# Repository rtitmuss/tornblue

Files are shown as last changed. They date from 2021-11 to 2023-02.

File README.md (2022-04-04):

# TornBlue - a bluetooth split keyboard

In this repo you can find information about the TornBlue a bluetooth split keyboard with SMT components. This is an iteration on the [Torn](https://github.com/rtitmuss/torn), which is a split keyboard using through hole components.

You can ask questions and get help on the [Torn Discord channel](https://discord.gg/mamAqNccju).

**WARNING: These files are provided as a reference for designing keyboard PCBs, without liability and without any guarantees regarding functionality. This is untested work in progress, really don't assume anything here will work.**

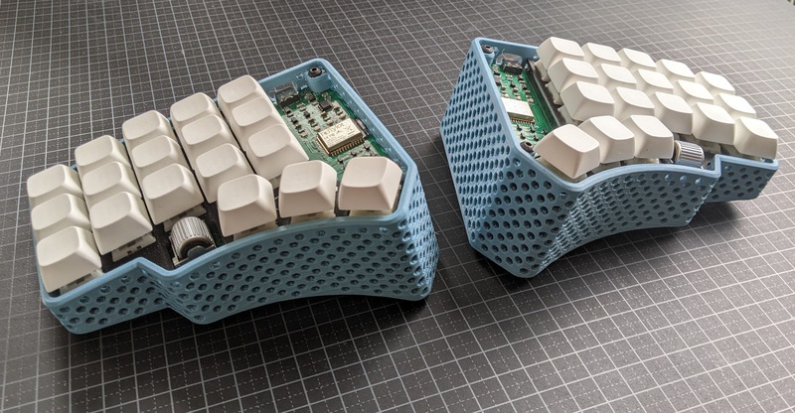
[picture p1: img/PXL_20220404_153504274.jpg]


## Features

- nRF52840 using [zmk](https://zmk.dev/) keyboard firmware
- Battery charging for a 3.7v lithium rechargeable battery (JST-PH connector)
- 6x3 or 5x3 layout with detachable outer column
- 3 leds and 1 charging led
-  ([SOIC test clip footprint](https://hackaday.com/2019/06/13/soicbite-a-program-debug-connector-for-an-soic-test-clip/)) for programming
- Breakout with switchable 3.3v and gpios
- Battery level reported over BT
- Supports soldered Cherry MX compatible or Kailh Choc key switches
- Horizontal reset button (case friendly) 
- JLCPCB PCBA (pcb assembly); handsoldering required for underglow leds and JST-PH connector 

Optional features:

- Underglow leds 
- Optional Panasonic EVQWGD001 wheel encoders

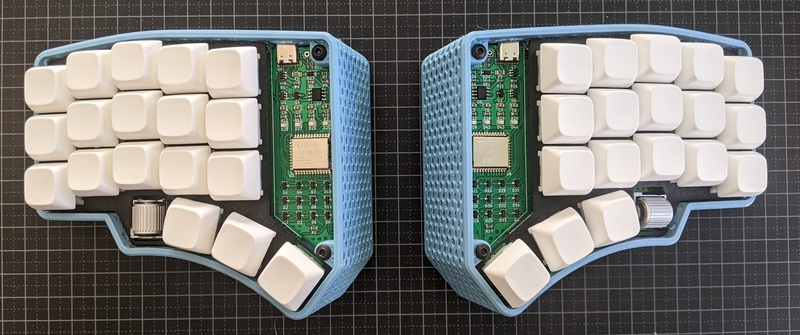
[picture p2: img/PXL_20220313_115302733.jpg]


## Parts required

- 2x assembled TornBlue Rev 1 PCBs
- 2x 3.7v lithium rechargeable battery with JST connector. **SAFETY NOTE: Only use a LiIon battery with over-charging and over-use protection. Check the battery polarity before connecting.**
- (Optional) 2x [JST-PH connector](https://www.electrokit.com/en/product/header-ph-2p-2mm-right-angle-smd/). 2mm pitch. Side entry. Surface-mounted.
- (Optional) 2 x [Panasonic EVQWGD001](https://www.aliexpress.com/wholesale?catId=0&initiative_id=SB_20210830111528&SearchText=Panasonic+EVQWGD001) wheel encoder
- (Optional) 12 x [WS2812B 5050 leds](https://www.aliexpress.com/wholesale?catId=0&initiative_id=SB_20210830111716&SearchText=WS2812B)
- (Optional) ST link v2 (or similar) and SOIC-8 test clip for programming the bootloader

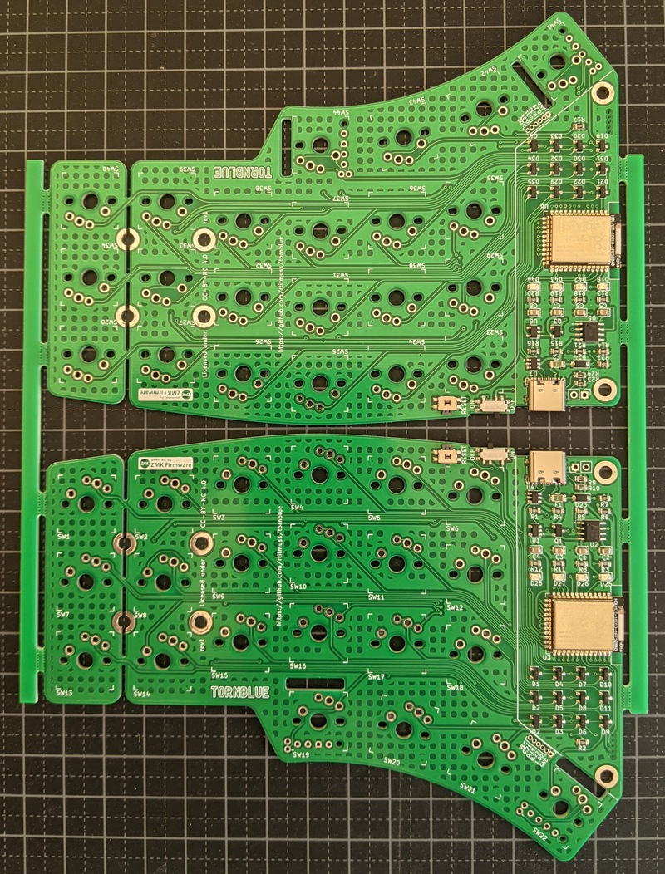
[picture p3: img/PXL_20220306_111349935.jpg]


## Build instructions

You can find full [build instructions](./build.md), and information for [different cases](./case/README.md).

## Components

The main components are:

- [Holyiot YJ-18010](http://www.holyiot.com/tp/2019042516322180424.pdf); this was chosen as it has castellated edges, which is easier hand soldering the module to the PCB.

- [XC6220](https://www.torexsemi.com/file/xc6220/XC6220.pdf); 3.3V voltage regulator to supply the Holyiot module.

- [TP4096](https://dlnmh9ip6v2uc.cloudfront.net/datasheets/Prototyping/TP4056.pdf) Li-Ion Battery Charger 

- [SRV05-4](https://www.onsemi.com/pdf/datasheet/srv05-4-d.pdf) ESD protection for the USB port
   
 - Other parts use 0805 and SOT-23 packages. These larger packages can be hand soldered and are similar sizes for a pleasing appearance. The parts have been laid out horizontally with a consistent polarity to simplify assembly.

## Reference designs

The following projects were used as reference designs.

- [ZMK hardware design guide](https://github.com/ebastler/zmk-designguide) (CERN Open Hardware Licence Version 2 - Permissive) - note the battery charging circuit might be unsafe, see this information about [TP4056](https://www.best-microcontroller-projects.com/tp4056.html)

- [isometria75](https://github.com/ebastler/isometria-75/tree/v2) (BSD 2-Clause License)

- [Unified USB type-C PCB](https://github.com/ebastler/unified-usb-pcb) (BSD 2-Clause License)

- [Nice!Nano](https://nicekeyboards.com/docs/nice-nano/pinout-schematic)

- [nRFMicro](https://github.com/joric/nrfmicro/wiki) (Public domain)

- [Adafruit nRF52840](https://learn.adafruit.com/introducing-the-adafruit-nrf52840-feather/downloads) (Creative Commons Attribution, Share-Alike)

## Showcase

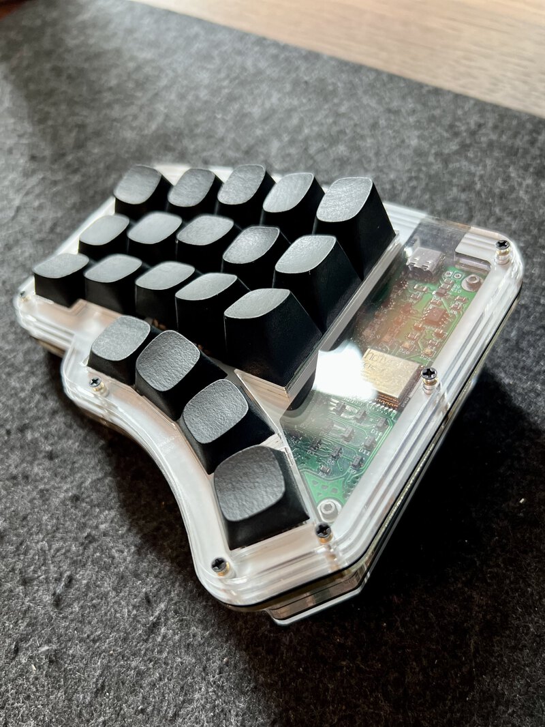
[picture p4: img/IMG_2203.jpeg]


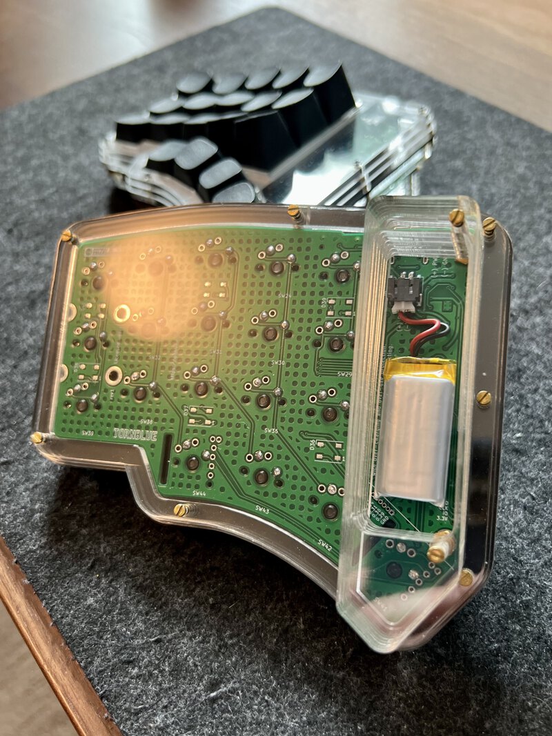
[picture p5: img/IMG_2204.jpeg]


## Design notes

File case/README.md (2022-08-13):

# Tornblue cases

The following case designs are available for Tornblue.

## 3D printed wedge case

This is a hi-pro style wedge case. You can download the [files and instructions](./wedge/README.md).



## Stacked Acrlyic Case

You can download the [files and instructions](./stacked-acrylic/README.md).

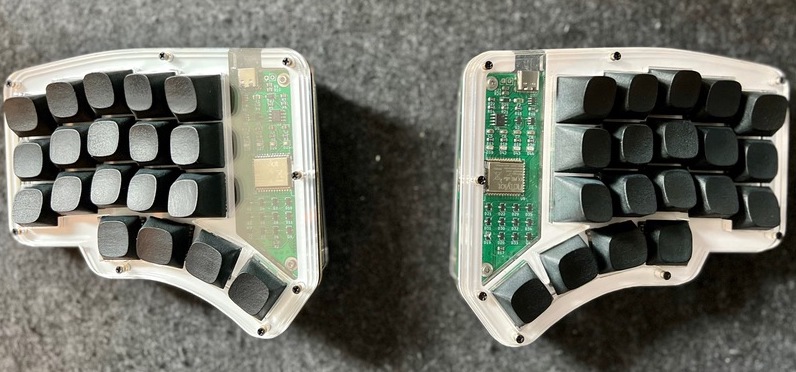
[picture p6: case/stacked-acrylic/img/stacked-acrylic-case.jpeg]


## Mini Wedge Case

This is a plateless wedge case. You can download the [files and instructions](./mini-wedge/README.md).

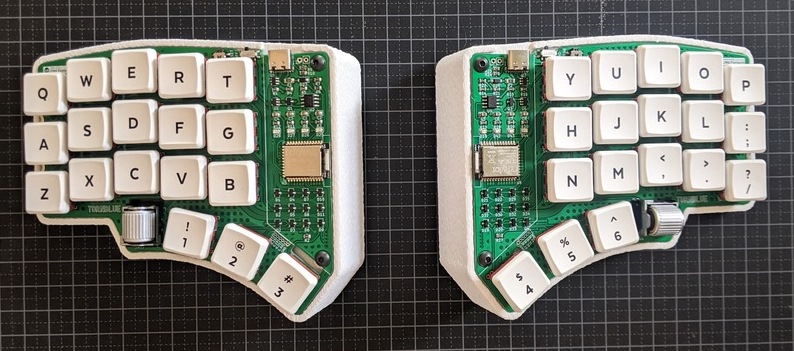
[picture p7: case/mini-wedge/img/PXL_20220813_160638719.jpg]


## Fusion 360 design files

If you want to make your own case designyou can use this [fusion 360 design file](./fusion360/tornblue r1.f3d). This design includes the KiCad 3d model and a basic sketch for the keyboard.

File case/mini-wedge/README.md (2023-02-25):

# Mini Wedge Case

This is a plateless wedge style case with a 14 degree angle for 5 column tornblue keyboards.

## 3d printing

### Case

You can 3d print a mini wedge case for your Tornblue using the follow files:

#### 5 column case
[Mini Wedge 5 column.3mf](Tornblue_Mini_Wedge_5col.3mf)

#### 6 column case
[Mini Wedge 6 column.3mf](Tornblue_Mini_Wedge_6col.3mf)

No supports are required for the base. Print the case as a mirror image for the right side. When the case has printed you need to add four M3 heat set inserts in the bottom of each half of the case. The prints below use a 'fuzzy skin' to add some texture to the sides of the case.

## Weights

You can optionally add up to 135g of weight in the bottom of the case. The case is designed to use car wheel balance weights, with sizes 10g: 23mm x 19mm. 5g: 12mm x 19mm. Height 4mm (including adhesive padding). For example: [US](https://www.amazon.com/Pit-Posse-Balancing-Weights-Adhesive/dp/B00OQWS98S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), [UK](https://www.amazon.co.uk/FIERCE-CYCLE-Balance-Weights-Motorcycle/dp/B07QQ539GV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), [SE](https://www.amazon.se/gp/product/B01GHKG18G/ref=ppx_yo_dt_b_asin_image_o00_s00?ie=UTF8&psc=1).

## Assembly

Place the completed PCB on the base, taking care not to trap the battery cable. Use four 6mm M3 button head screws to attach the PCB to the base. Add adhesive feet to the underneath of the case.

Your keyboard is now finished, enjoy!


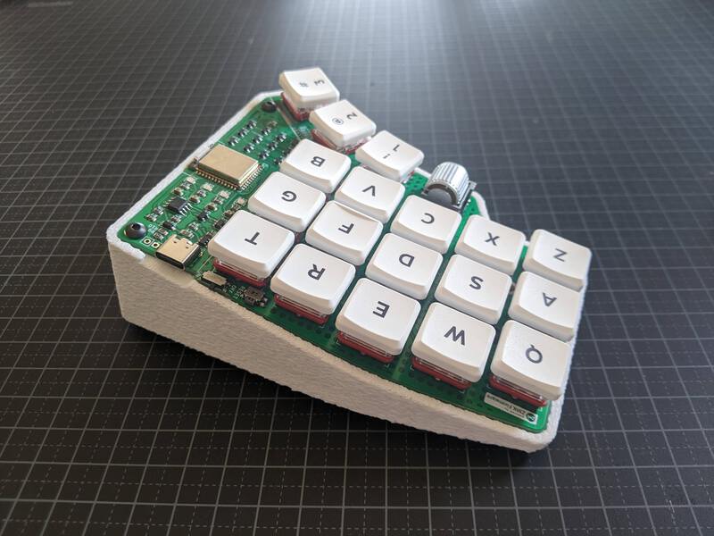
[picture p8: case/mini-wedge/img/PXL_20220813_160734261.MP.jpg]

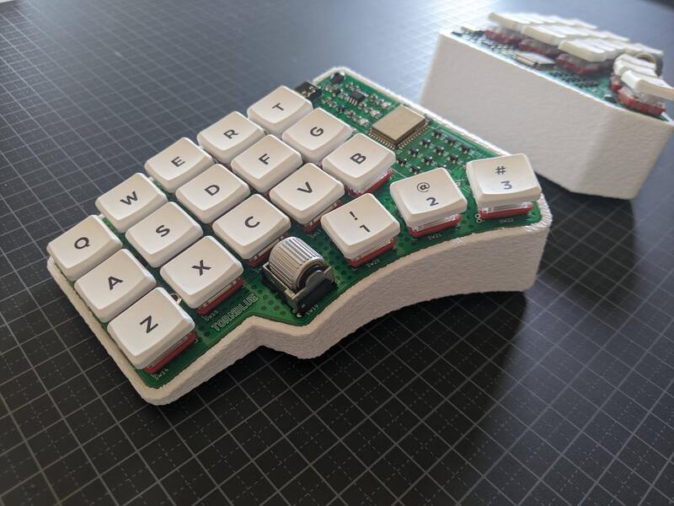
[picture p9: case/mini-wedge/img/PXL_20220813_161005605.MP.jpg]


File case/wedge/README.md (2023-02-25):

# 3d Printed Wedge Case

This is a wedge style case with a 14 degree angle for 5 column tornblue keyboards.

## 3d printing

### Plate

There is an optional 3d printable plate for MX switches. Remember to print and fit this before soldering your switches. The plate has cutouts for the roller encoder.

#### 5 column plate
[Wedge 5 column Plate.3mf](Tornblue_Wedge_5col_Plate.3mf)

#### 6 column plate
[Wedge 6 column Plate.3mf](Tornblue_Wedge_6col_Plate.3mf)

### Case

You can 3d print a wedge case for your Tornblue using the follow files:

No supports are required for the base.

The edge prints upside down so the visible surface is on the print bed. You need to print with supports.

#### 5 column case
[Wedge 5 column Base.3mf](Tornblue_Wedge_5col_Base.3mf)

[Wedge 5 column Edge.3mf](Tornblue_Wedge_5col_Edge.3mf)

#### 6 column case
[Wedge 6 column Base.3mf](Tornblue_Wedge_6col_Base.3mf)

[Wedge 6 column Edge.3mf](Tornblue_Wedge_6col_Edge.3mf)

## Post processing

You need to do some post processing on the case wall. Remove the support from the top of the case and clean up the bridging by the USB connector and switch holes. Give the case a good rub to remove any stray fibers.

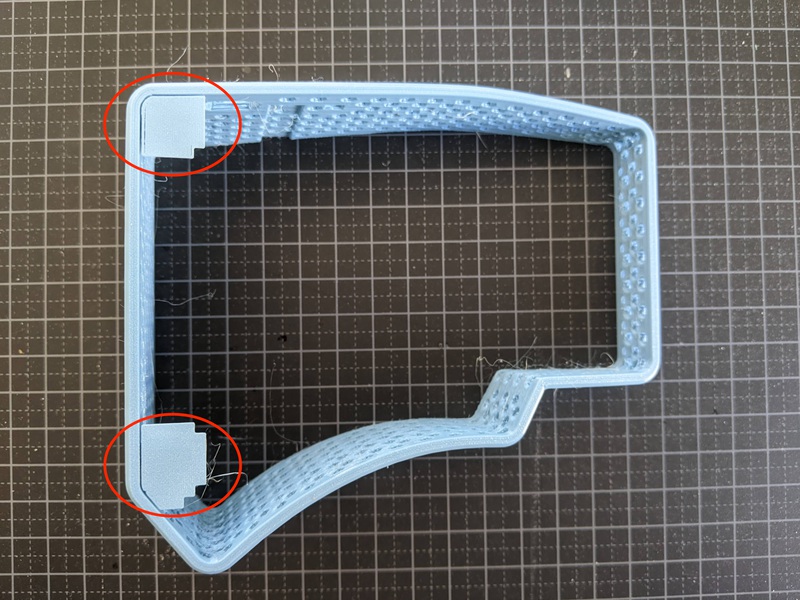
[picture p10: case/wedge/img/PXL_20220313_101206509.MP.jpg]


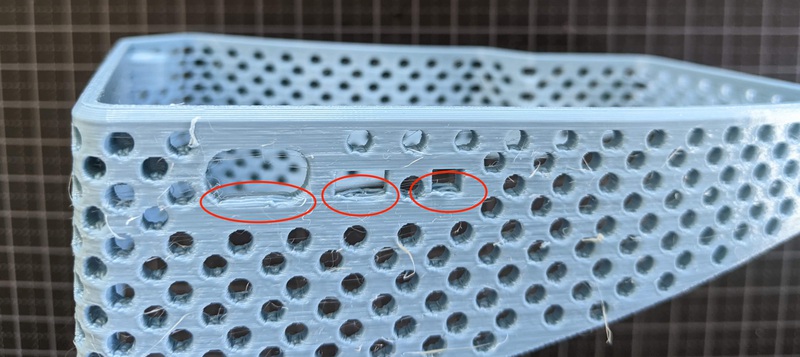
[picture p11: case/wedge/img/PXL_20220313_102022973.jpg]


Add four M3 heat set inserts in the bottom of each half of the case.

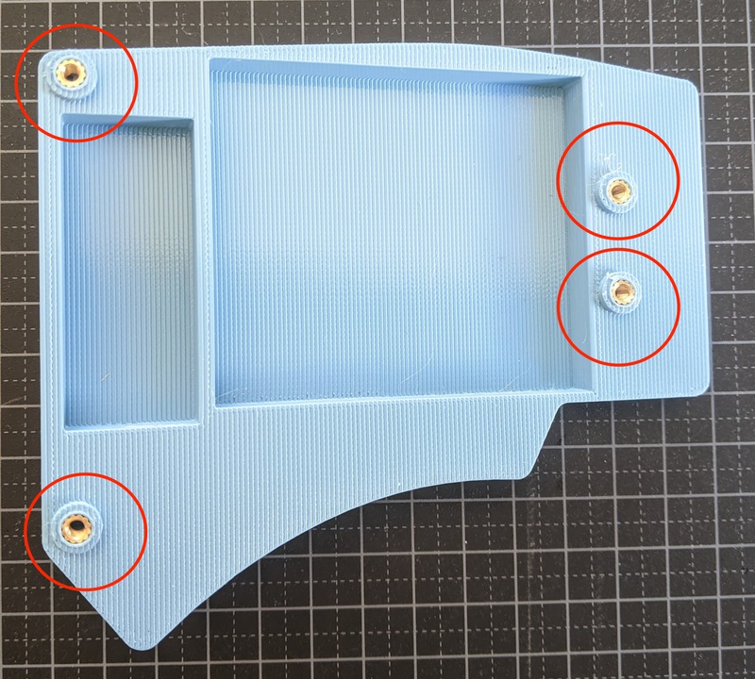
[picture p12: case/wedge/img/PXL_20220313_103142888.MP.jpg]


## Weights

You can optionally add up to 180g of weight in the bottom of the case. The case is designed to use car wheel balance weights, with sizes 10g: 23mm x 19mm. 5g: 12mm x 19mm. Height 4mm (including adhesive padding). For example: [US](https://www.amazon.com/Pit-Posse-Balancing-Weights-Adhesive/dp/B00OQWS98S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), [UK](https://www.amazon.co.uk/FIERCE-CYCLE-Balance-Weights-Motorcycle/dp/B07QQ539GV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), [SE](https://www.amazon.se/gp/product/B01GHKG18G/ref=ppx_yo_dt_b_asin_image_o00_s00?ie=UTF8&psc=1).

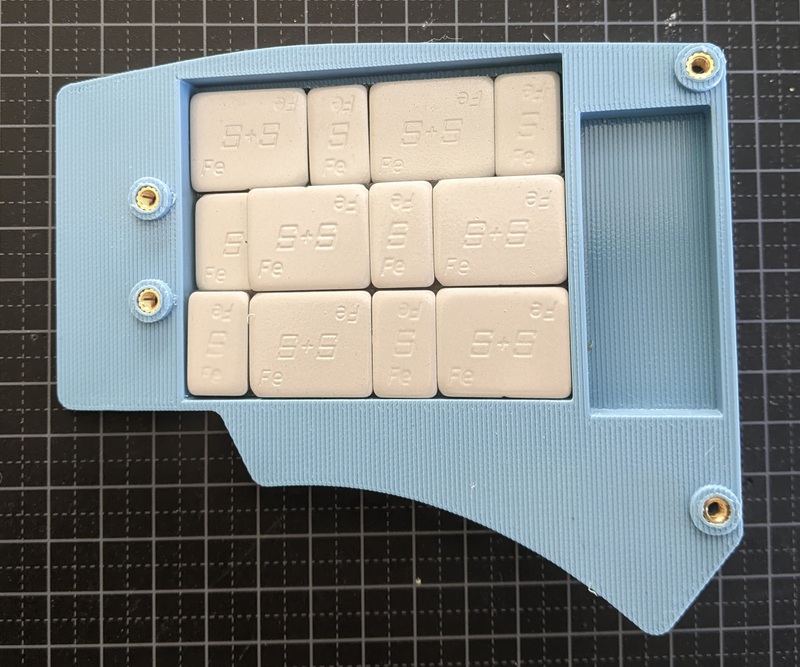
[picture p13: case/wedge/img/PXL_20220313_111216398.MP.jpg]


## Assembly

Place the completed PCB on the base, taking care not to trap the battery cable. Use two 6mm M3 button head screws to attach the PCB to the base as shown below.

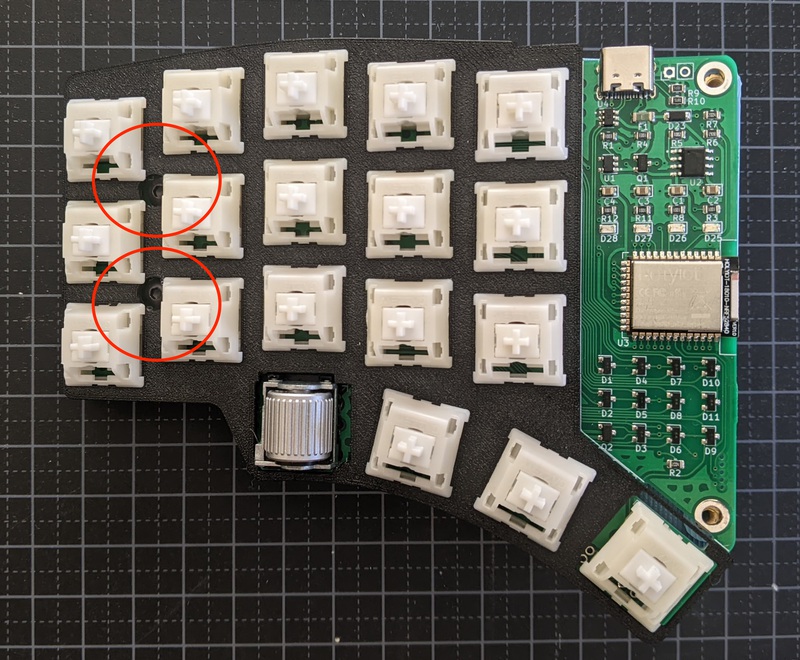
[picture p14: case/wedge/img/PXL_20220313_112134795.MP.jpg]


Carefully slide the case wall over the base. Check the clearance near the on/off switch. Use two 16mm M3 button head screws to swecure the top of the case.

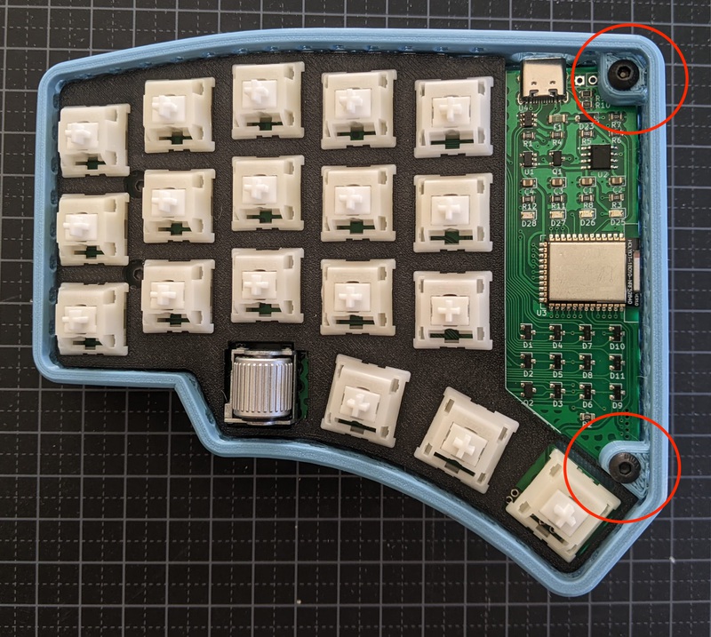
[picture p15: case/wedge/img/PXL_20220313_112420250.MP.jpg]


Add adhesive feet to the underneath of the case.

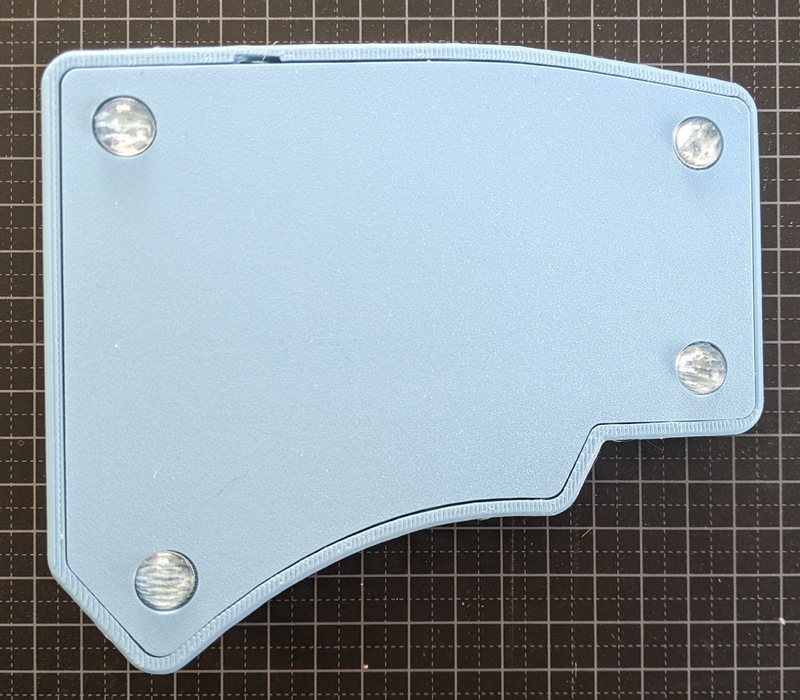
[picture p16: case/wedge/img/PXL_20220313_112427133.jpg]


Your keyboard is now finished, enjoy!



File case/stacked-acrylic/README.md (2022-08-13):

# Stacked Acrylic Plate Case

This is a high-profile case made of a stack of laser-cut acrylic/metal sheets. It supports a 5 column TornBlue keyboard. An optional stack of layers can be used to add tenting and store the battery.

With the exception of the switch plate, each layer is cut from 3mm acrylic. The switch plate is 1.5-1.6mm and can be cut from either acrylic or metal.

[Fusion 360 File](./StackedAcrylicCase.f3d)

In addition to the layers you will need screws and standoffs to mount the layers:

- 40 M3 x 6mm screws
- 16 M3 x 12mm standoffs

For the tenting legs you will need:

- 8 M3 x 6mm screws
- 4 M3 x 21mm standoffs (may need to adjust if you add or remove layers)

## Images


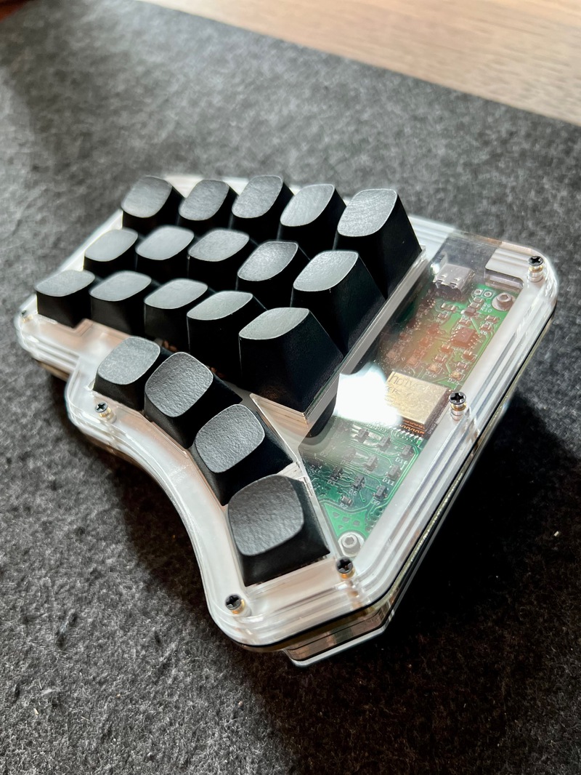
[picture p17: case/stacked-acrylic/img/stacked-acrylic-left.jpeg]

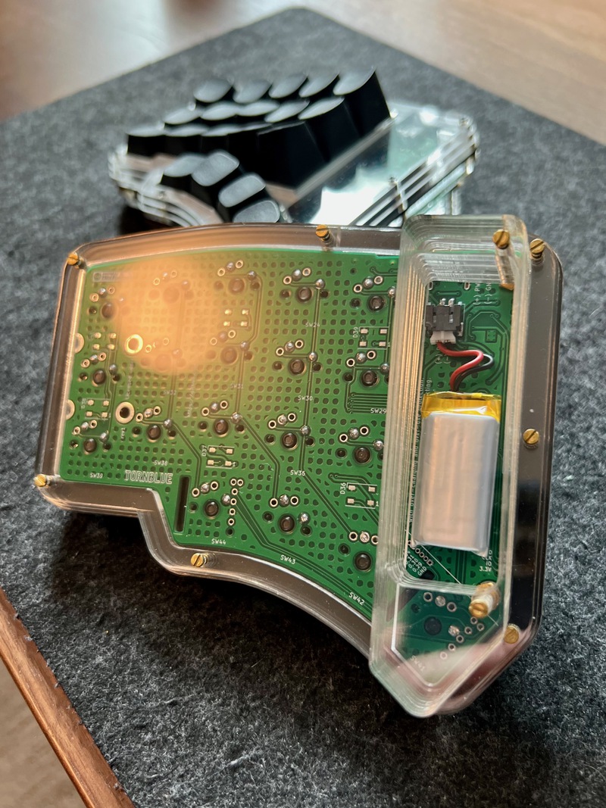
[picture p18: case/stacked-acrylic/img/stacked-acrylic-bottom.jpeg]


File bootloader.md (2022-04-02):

# Bootloader

There are main options for programming nRF52540 boards, and these are well documented at [https://github.com/joric/nrfmicro/wiki/Bootloader](https://github.com/joric/nrfmicro/wiki/Bootloader). To program the tornblue I used a ST-Link/V2 with the Blackmagic firmware on OS X.

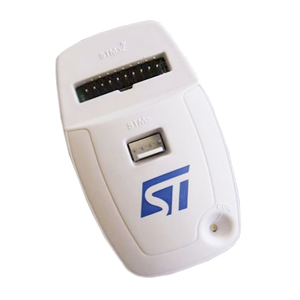
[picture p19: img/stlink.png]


## Installing the blackmagic firmware
To install the blackmagic firmware on the ST-Link/V2 you need to first download and compile the following tool and firmware:

-   [https://github.com/UweBonnes/stlink-tool/tree/stlinkv21](https://github.com/UweBonnes/stlink-tool/tree/stlinkv21)
-   [https://github.com/blacksphere/blackmagic/tree/master/src/platforms/stlink](https://github.com/blacksphere/blackmagic/tree/master/src/platforms/stlink)

Install the blackmagic firmware on the ST-Link/V2 using:

	$ ./stlink-tool/stlink-tool blackmagic/src/blackmagic.bin
	Firmware version : V2J31S7 
	Loader version : 14152 
	ST-Link ID : 52FF68064885555248171987 
	Firmware encryption key : A32E6E6E82ADAF7D99EBD574CB4C784D 
	Current mode : 1 Loaded firmware : blackmagic/src/blackmagic.bin, size : 97332 bytes 
	................................................................................................

# Tornblue bootloader

Like many ZMK boards Tornblue uses the Adafruit_nRF52_Bootloader. I modified this for tornblue so that one LED is enabled in the bootloader. You can download this version from [https://github.com/rtitmuss/Adafruit_nRF52_Bootloader](https://github.com/rtitmuss/Adafruit_nRF52_Bootloader).

Compile the bootloader using:

	$ make BOARD=tornblue

You can find the compiled bootloader at:

	_build/build-tornblue/tornblue_bootloader-0.6.3-49-gbfd3b24.out

# Connecting the programmer

You can connect the programmer to the tornblue using a SOIC connector. Connect the SWD pads on the PCB to the 20 pin JTAG header on the ST-Link/V2 as follows:  

|PCB SWD|ST-Link/V2  |  
|--|--|
|3.3V|VCC Pin 1|  
|SWD IO|SWDIO Pin 7|  
|SWD CLK|SWCLK Pin 9|  
|GND|GND Pin 8|

The pinout on the ST-Link/V2 20 pin JTAG header is:

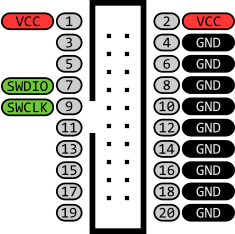
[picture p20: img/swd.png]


# Programming the bootloader

You always need to setup the ST-Link/V2 after it has been powered up using:

    ./stlink-tool/stlink-tool 

When the ST-Link/V2 is first connected all the three green LEDs on the Tornblue may all be lit.

You can first check the that board is correctly connected using `swdp_scan` as shown below. You may need to update the /dev path.

    $ arm-none-eabi-gdb --batch -ex "target extended-remote /dev/cu.usbmodem14101" -ex "mon swdp_scan"
    Target voltage: 3.30V
    Available Targets:
    No. Att Driver
     1      Nordic nRF52 Access Port (protected)
     
You can then program the bootloader, using:

    $ arm-none-eabi-gdb --batch -ex "target extended-remote /dev/cu.usbmodem14101" -ex "mon swdp_scan" -ex "file tornblue_bootloader-0.6.3-49-gbfd3b24_s140_6.1.1.hex" -ex "att 1" -ex "mon erase" -ex load
    Target voltage: 3.30V
    Available Targets:
    No. Att Driver
     1      Nordic nRF52 Access Port (protected) 
    warning: while parsing target description: no element found
    warning: Could not load XML target description; ignoring
    warning: while parsing target memory map (at line 1): Required element <memory> is missing
    0xbfefed14 in ?? ()
    Loading section .sec1, size 0xb00 lma 0x0
    Loading section .sec2, size 0xf000 lma 0x1000
    Loading section .sec3, size 0x10000 lma 0x10000
    Loading section .sec4, size 0x5de8 lma 0x20000
    Loading section .sec5, size 0x85b4 lma 0xf4000
    Loading section .sec6, size 0x58 lma 0xfd800
    Loading section .sec7, size 0x8 lma 0x10001014
    Start address 0xfafcc, load size 188156
    Transfer rate: 418 KB/sec, 969 bytes/write.
    [Inferior 1 (Remote target) detached]

I found that I needed to program the bootloader twice for it to be successful.

    $ arm-none-eabi-gdb --batch -ex "target extended-remote /dev/cu.usbmodem14101" -ex "mon swdp_scan" -ex "file tornblue_bootloader-0.6.3-49-gbfd3b24_s140_6.1.1.hex" -ex "att 1" -ex "mon erase" -ex load
    Target voltage: 3.30V
    Available Targets:
    No. Att Driver
     1      Nordic nRF52 M4
     2      Nordic nRF52 Access Port 
    0xfffffffe in ?? ()
    erase..
    Loading section .sec1, size 0xb00 lma 0x0
    Loading section .sec2, size 0xf000 lma 0x1000
    Loading section .sec3, size 0x10000 lma 0x10000
    Loading section .sec4, size 0x5de8 lma 0x20000
    Loading section .sec5, size 0x85b4 lma 0xf4000
    Loading section .sec6, size 0x58 lma 0xfd800
    Loading section .sec7, size 0x8 lma 0x10001014
    Start address 0xfafcc, load size 188156
    Transfer rate: 31 KB/sec, 959 bytes/write.
    [Inferior 1 (Remote target) detached]

When the booloader has been successfully installed then the a single green LED will be lit.

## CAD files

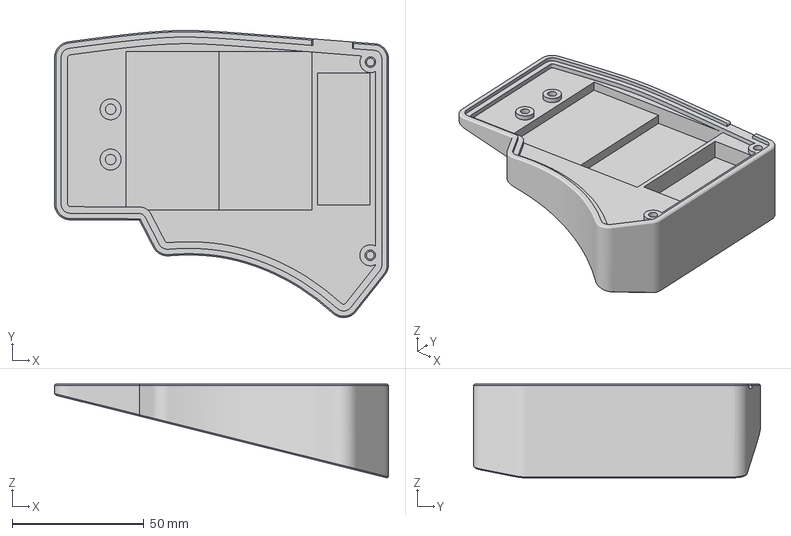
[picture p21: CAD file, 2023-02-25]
case/mini-wedge/Tornblue_Mini_Wedge_5col.3mf
126.7 x 108.9 x 35.6 mm

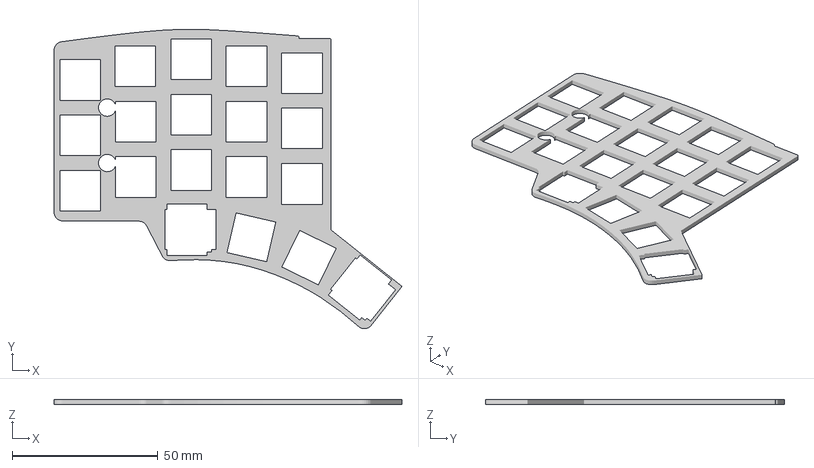
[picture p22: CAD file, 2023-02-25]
case/wedge/Tornblue_Wedge_5col_Plate.3mf
119.6 x 102.9 x 1.60 mm

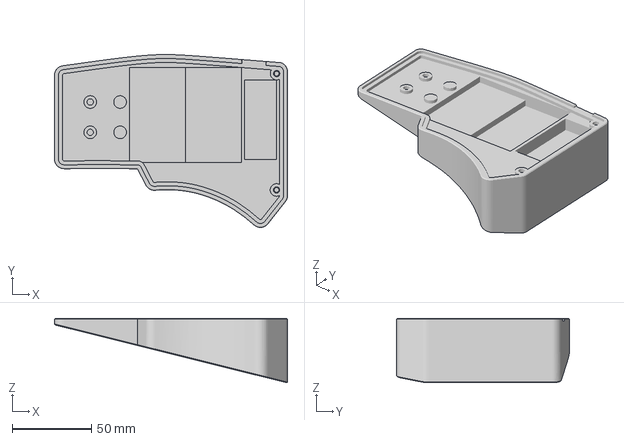
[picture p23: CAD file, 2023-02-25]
case/mini-wedge/Tornblue_Mini_Wedge_6col.3mf
146.7 x 108.9 x 40.6 mm

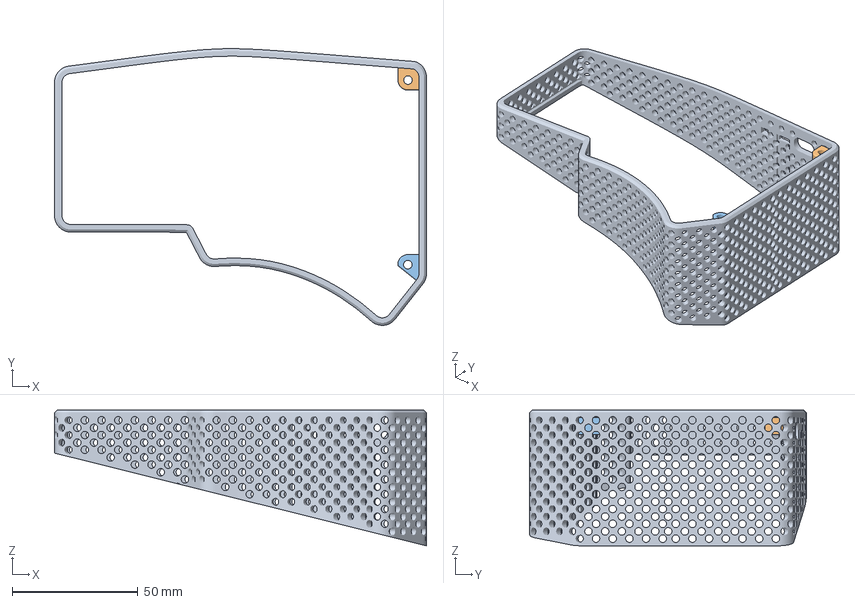
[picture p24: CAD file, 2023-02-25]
case/wedge/Tornblue_Wedge_6col_Edge.3mf
147.7 x 109.9 x 53.9 mm

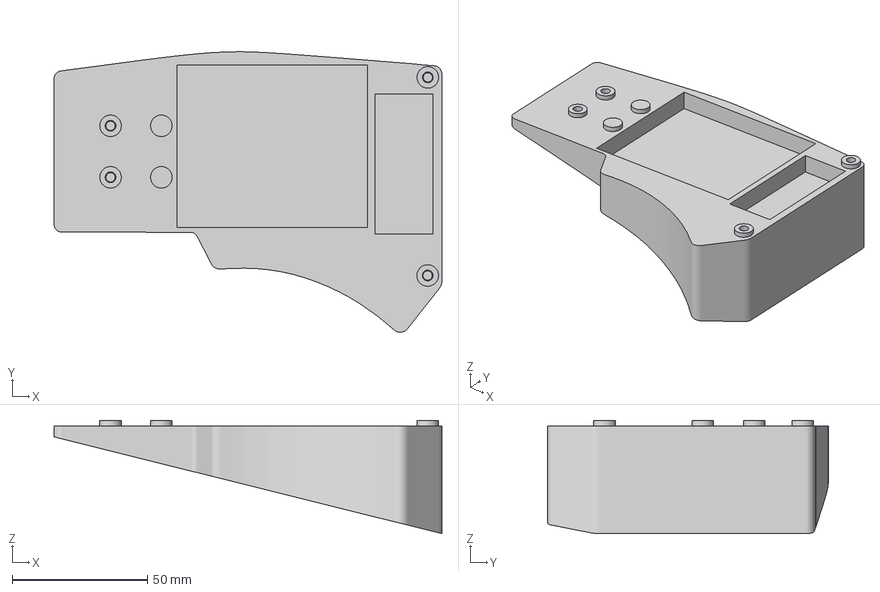
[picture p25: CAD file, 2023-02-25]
case/wedge/Tornblue_Wedge_6col_Base.3mf
143.5 x 103.8 x 41.9 mm

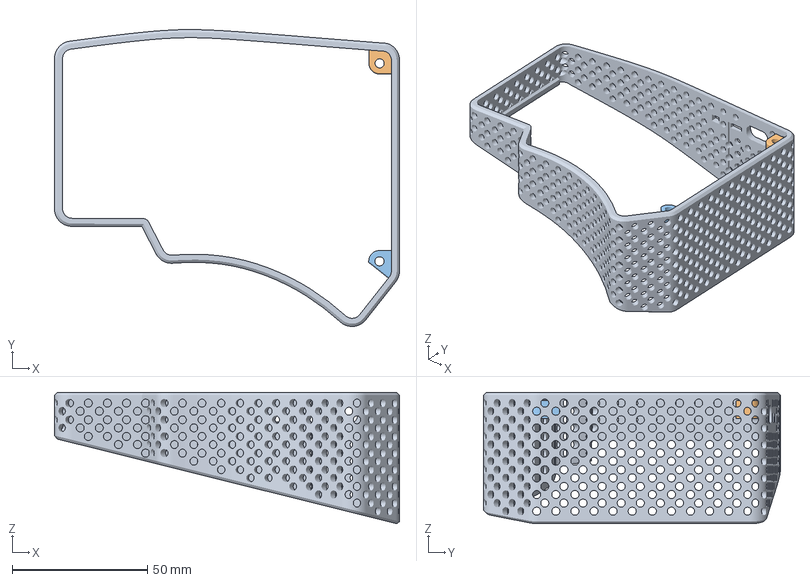
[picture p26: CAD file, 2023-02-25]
case/wedge/Tornblue_Wedge_5col_Edge.3mf
127.7 x 109.9 x 48.6 mm

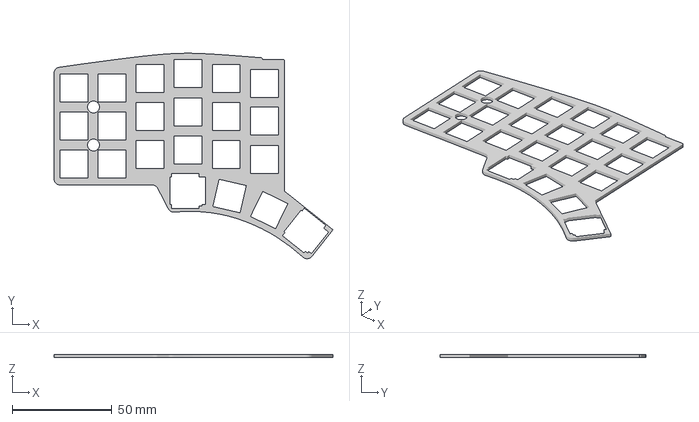
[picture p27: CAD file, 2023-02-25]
case/wedge/Tornblue_Wedge_6col_Plate.3mf
139.6 x 102.9 x 1.60 mm

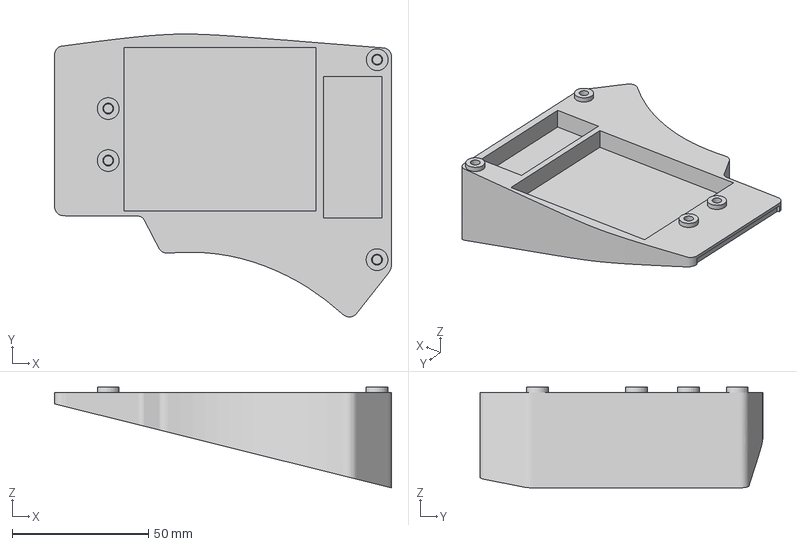
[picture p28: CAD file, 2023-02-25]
case/wedge/Tornblue_Wedge_5col_Base.3mf
123.5 x 103.7 x 36.9 mm

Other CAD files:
case/fusion360/tornblue r1.f3d
case/stacked-acrylic/StackedAcrylicCase.f3d

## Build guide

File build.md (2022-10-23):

# Build Instructions

There are the build instructions for the Tornblue keyboard.

## PCBs

The PCBs have been ordered using PCBA, or PCB assembly. This means that most components have been installed during manufacturing.

There are some optional components that need to be hand soldered on the underside of the board, the JST-PH battery connector and underglow LEDs. You will also need to solder the keyswitches and optional roller encoders.

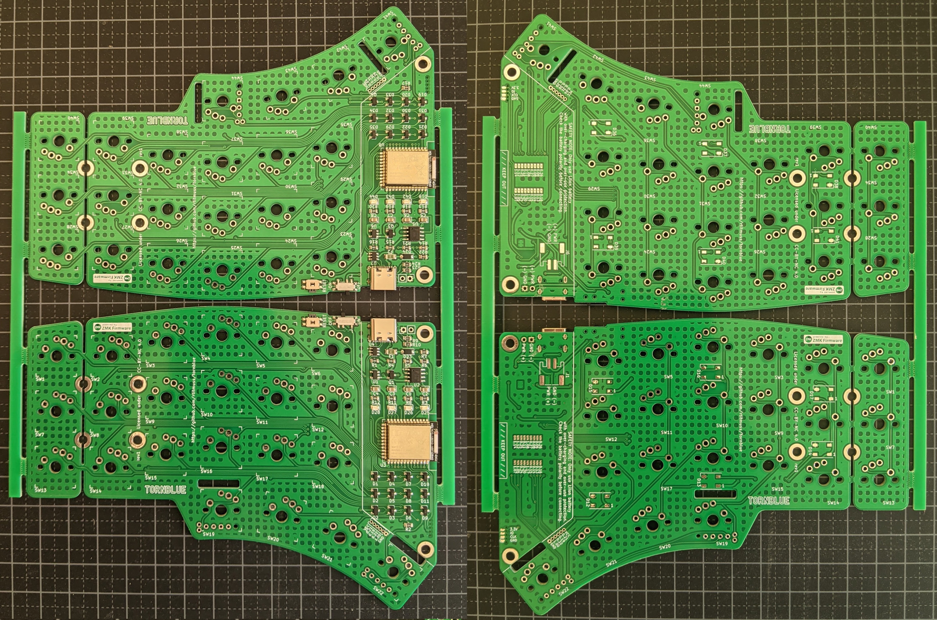
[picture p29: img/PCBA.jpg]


### Depanelization 

The left and right PCBs have been manufactured as a single panel. First you need to remove the breakaway tabs, to get a clean cut you can use wire cutters and a file (for example see this [PCB Depaneling](https://www.youtube.com/watch?v=NLKeF43AOBY&t=121s) video).

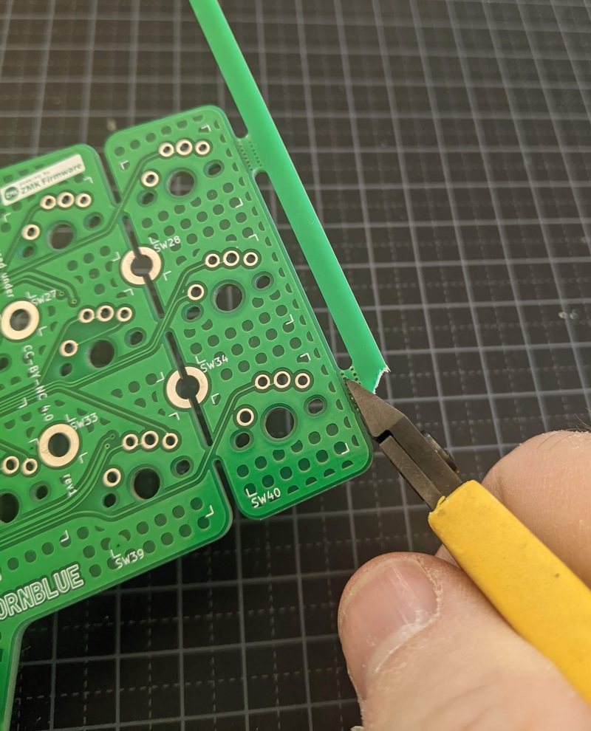
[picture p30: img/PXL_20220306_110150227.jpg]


### 5 or 6 columns

If you are building a 5 column Tornblue keyboard you also need to break off the outer column.

### Underglow LEDs (optional)

The WS2812B 5050 leds need to be soldered in the **correct orientation**, on the underside of the board. There is a mark on one corner of the leds, this should be pointing to the top left of the PCB - next to the small vertical mark on the silkscreen. Carefully solder all six WS2812B leds.

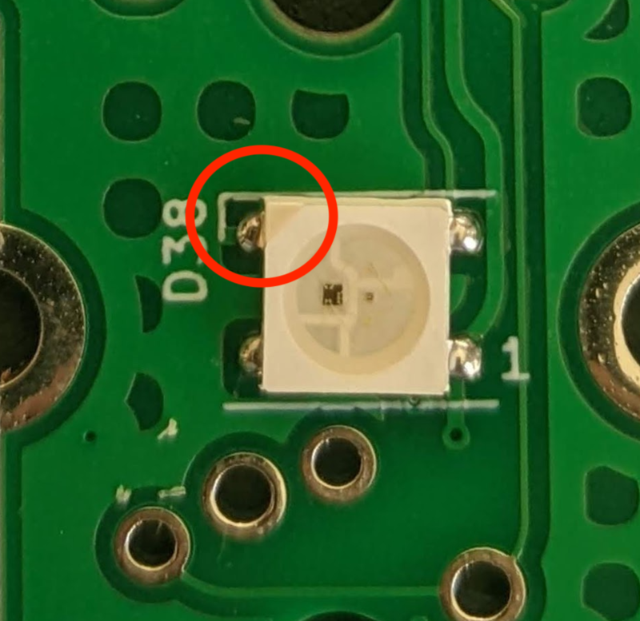
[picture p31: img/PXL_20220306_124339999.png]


### JST-PH connector (optional)

The JST-PH connector can be used for the battery connection, it is also possible to solder the battery with the through hole connectors near the USB port. **Do not connect the battery yet!**

The JST-PH connector is soldered on the underneath of the PCB.  The two pads towards the top of the board connect the battery, and the lower two pads are for mechanical support.

First apply some solder to one of the pads (as shown in the picture below). Reheat the solder and slide the JST-PH connector in place. Check the connector is correctly positioned, and adjust if required. Then solder the remaining three pads.

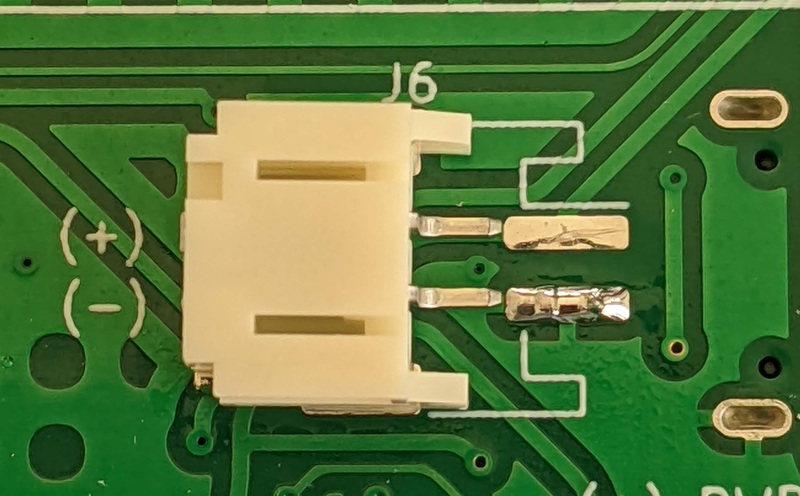
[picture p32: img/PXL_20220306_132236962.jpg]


## Bootloader

If you bought boards directly from rtitmuss then bootloader is pre-programmed on the board. 

If you are using your own boards then you will need to program the bootloader yourself before installing ZMK. [See how to program the bootloader](./bootloader.md). 

## ZMK

You can now install zmk.



_The tornblue board configuration is not yet included in the zmk repo, you need to download zmk from https://github.com/rtitmuss/zmk_

#### Building with github actions

(todo)

#### Building on your PC

To build the firmware on your PC follow the [zmk installation instructions](https://zmk.dev/docs/development/setup).

Once thats done, checkout tornblue and move to the /app dir
	
	git checkout tornblue_r1
	cd app

You can build zmk for the left side of the keyboard using:

	west build -p -d build/tornblue_left -b tornblue_left -- -DZMK_CONFIG=/Users/richardt/keyboard/miryoku-zmk-config/config/

You can build zmk for the right side of the keyboard using:

	west build -p -d build/tornblue_right -b tornblue_right

### Install zmk

Connect the left side of the keyboard with USB. Press the reset button quickly twice. You should see a USB drive called `NRF52BOOT`. Copy the `zmk.uf2` from the `tornblue_left` build folder. zmk will be installed and the keyboard will restart.

Repeat this with the right side of the keyboard, but copy the `zmk.uf2` file from the `tornblue_right` build folder.

### Test

You can now test the PCBs. Power both sides of your keyboard to your PC with two USB cables Use tweezers or similar to short the key switch pads and test that all the keys work, on both sides of the keyboard. Note you don't need to pair the bluetooth yet the keycodes will be sent over USB.

## Key switches and battery

### Encoder (optional)

You can optionally use a Panasonic EVQWGD001 horizontal encoder. Position the encoder clip at an angle on the PCB, and carefully rotate it down. Solder the pins.

_ZMK currently only supports the encoder on the left side of the keyboard. A patch is needed to support encoders on both sides._

### Key switches

You can solder either Cherry MX compatible or Kailh Choc key switches. If you plan to use a plate remember to insert the key switches before soldering.

### Battery

If you are using the JSP PH connector you can now plug your battery on the underside of the PCB. **The red wire MUST connect to the positive terminal marked 'PWR (+)'**.

Alternatively you can solder the battery directly to the PCB using the through holes near the USB connector. **Be  very careful not to short the battery connectors.**

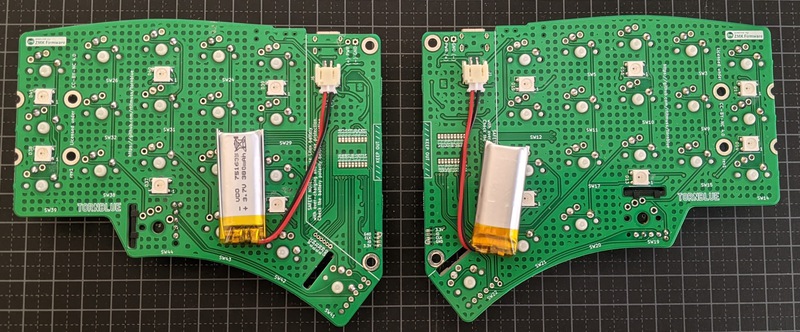
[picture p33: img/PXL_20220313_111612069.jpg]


## Your finished

The PCB assembly if now complete. You can use one of the [case designs](./case/README.md), or make your own.

You can now use your new Bluetooth tornblue keyboard by pairing it with your PC, and customising zmk as required.

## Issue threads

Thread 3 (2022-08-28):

Question: Coin battery Fork

rafaeldelboni, 2022-08-28:
I was planning to build this project to make a single PCB keyboard with choc switches (ferris like), but with the current battery is very hard to have something nice looking without the case.

So I was thinking to fork this and replace the current battery and use a coin battery in the space of the rotary encoder.

Lithium Battery CR2032 210mAh
https://a.aliexpress.com/_mOBfcmy

Battery Holder
https://a.aliexpress.com/_mt0Ty5w

Do you think is possible? How hard would be?

rtitmuss, 2022-08-28:
I don't think that would work, as these are non rechargeable batteries (any
maybe also the wrong voltage). You would need to make significant changes,
for example removing the battery charging chip. I would also be concerned
about the battery life. There are some keyboards that use a CR2032, and I
think these are typically paired with a dongle.

I did consider using a LIR2032, which is rechargeable, but it had a very
big footprint and didn't work atheistically.

On Sun, Aug 28, 2022 at 3:22 AM Rafael Delboni ***@***.***>
wrote:

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

rafaeldelboni, 2022-08-29:
Thanks for the clarification and all your work for the community.

Closed 2022-08-29.

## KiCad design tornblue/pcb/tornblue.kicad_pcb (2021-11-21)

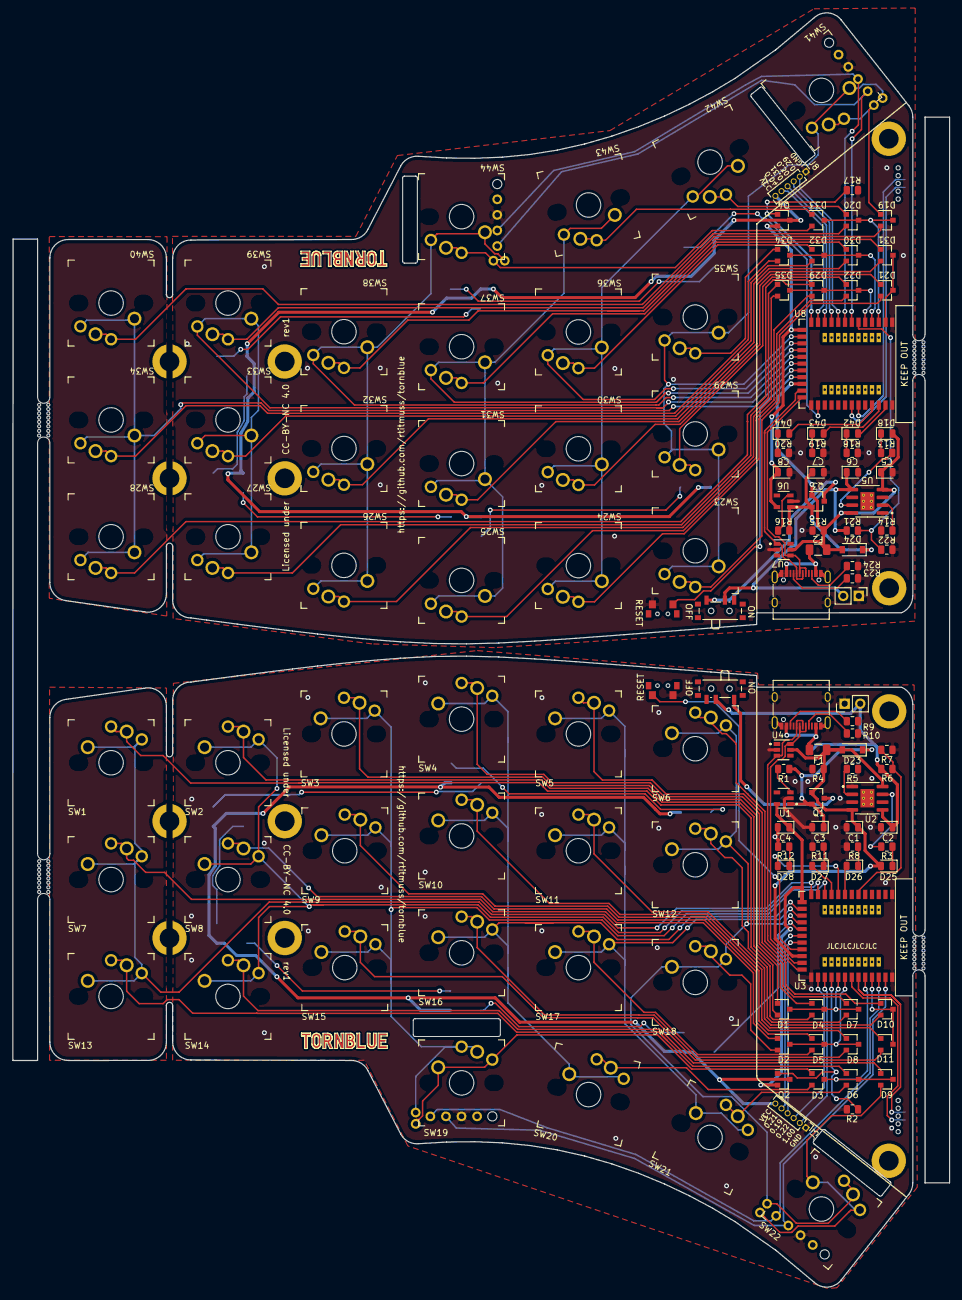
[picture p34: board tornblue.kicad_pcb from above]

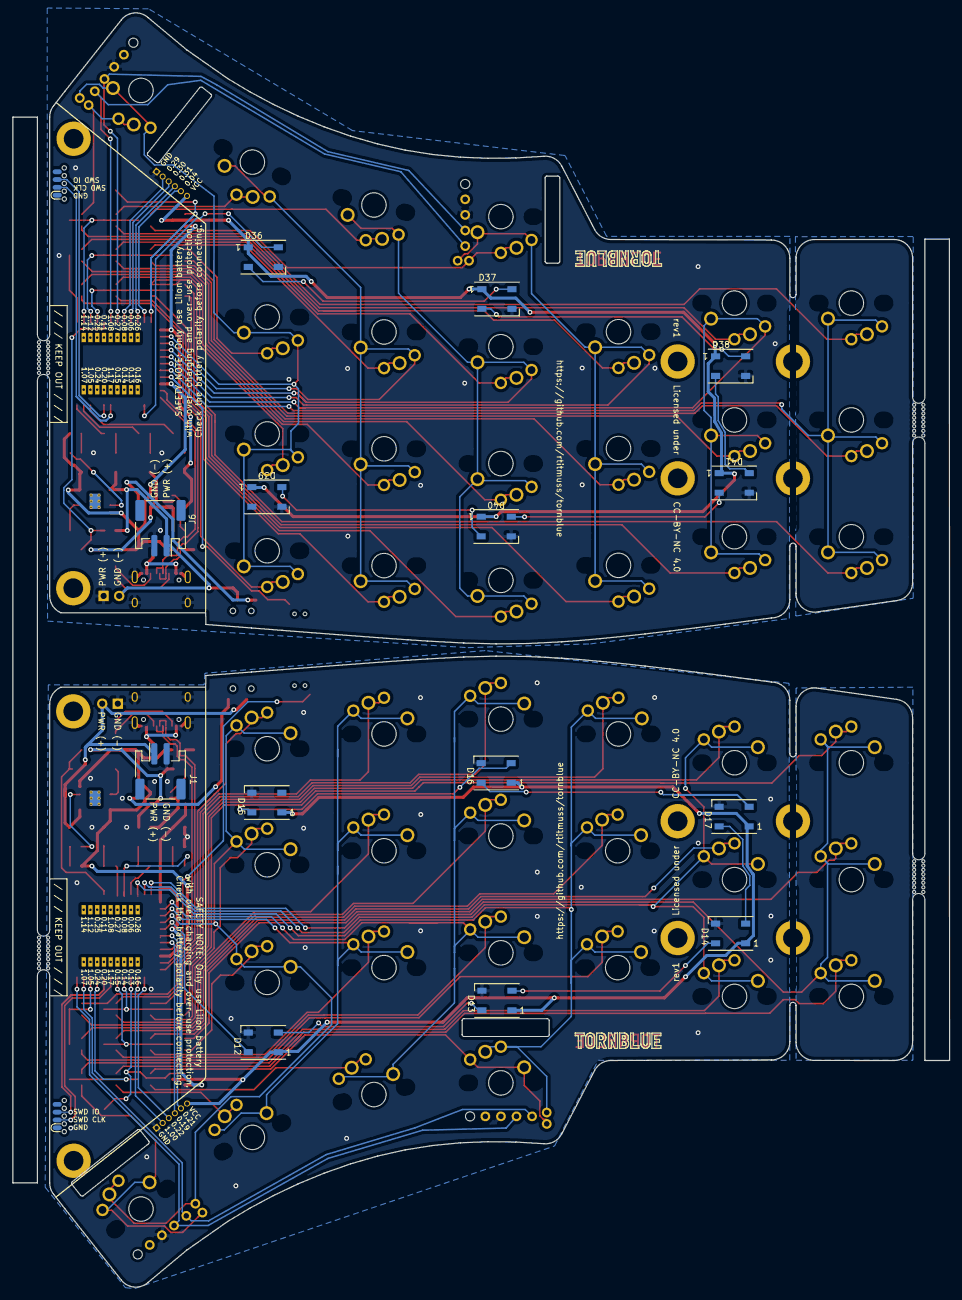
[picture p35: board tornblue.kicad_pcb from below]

Board: 2 copper layers, 152.7 x 207.8 mm, 164 parts (16 on the bottom side), 142 nets.

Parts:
C1, C2, C3, C4, C5, C6, C7, C8: 10uF; D_0805_2012Metric
D1, D2, D3, D4, D5, D6, D7, D8, D9, D10, D11, D19, D20, D21, D22, D29, D30, D31, D32, D33, D34, D35: BAV70_Small; SOT-23
D12, D13, D14, D15, D16, D17, D36, D37, D38, D39, D40, D41: WS2812B; LED_WS2812B_PLCC4_5.0x5.0mm_P3.2mm
D18, D25: BLUE; LED_0805_2012Metric
D23, D24: B5819W; D_SOD-123
D26, D27, D28, D42, D43, D44: GREEN; LED_0805_2012Metric
F1, F2: 750mA; Fuse_1206_3216Metric
H1, H2, H3, H4, H7, H8, H9, H10: MountingHole; MountingHole_3.2mm_M3_DIN965_Pad
H5, H6, H11, H12: MountingHole; MountingHole_3.2mm_M3_DIN965_Pad_Slot
J1, J6: BATT; JST_PH_S2B-PH-SM4-TB_1x02-1MP_P2.00mm_Horizontal
J2, J9: SWD; SOIC_clipProgSmall
J3, J8: BREAKOUT; PinHeader_1x06_P1.27mm_Vertical
J4, J10: USB C - USB2.0; USB_C_Receptacle_XKB_U262-16XN-4BVC11
J5, J7: BATT_PIN; PinHeader_1x02_P2.54mm_Vertical
Q1, Q2, Q3, Q4: AO3401A; SOT-23
R1, R4, R15, R16: 100k; R_0805_2012Metric
R2, R7, R17, R22: 2M; R_0805_2012Metric
R3, R8, R11, R12, R13, R18, R19, R20: 1k; R_0805_2012Metric
R5, R14: 10k; R_0805_2012Metric
R6, R21: 806k; R_0805_2012Metric
R9, R10, R23, R24: 5.1k; R_0805_2012Metric
SW1, SW2, SW3, SW4, SW5, SW6, SW7, SW8, SW9, SW10, SW11, SW12, SW13, SW14, SW15, SW16, SW17, SW18, SW20, SW21, SW23, SW24, SW25, SW26, SW27, SW28, SW29, SW30, SW31, SW32, SW33, SW34, SW35, SW36, SW37, SW38, SW39, SW40, SW42, SW43: SW_Push; MX_PG1350_optional
SW19, SW22: EC11; MX_PG1350_EVQWGD001_LR_optional
SW41, SW44: EC11; MX_PG1350_EVQWGD001_UD_optional
SW50, SW52: SW_SPST; SW_SPDT_PCM12
SW51, SW53: RESET; SW_SPST_TS24CA
U1, U6: XC6220; SOT-23-5
U2, U5: TP4056; SOIC-8-1EP_3.9x4.9mm_P1.27mm_EP2.29x3mm_ThermalVias
U3, U8: nRF52840_holyiot_18010
U4, U7: SRV05-4; SOT-23-6
mouse-bite-5mm-slot, mouse-bite-5mm-slot#2, mouse-bite-5mm-slot#3, mouse-bite-5mm-slot#4: VAL**; mouse-bite-5mm-slot

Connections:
+3.3VP: C8.1, Q4.2, U6.5, U8.14
+3V3: C4.1, Q2.2, U1.5, U3.14
+5V: C1.1, D23.2, D25.2, F1.1, Q1.1, R4.1, U2.4, U2.8, U3.22, U4.5
+5VP: C5.1, D18.2, D24.2, F2.1, Q3.1, R15.1, U5.4, U5.8, U7.5, U8.22
COL0: SW1.1, SW7.1, SW13.1, U3.13
COL1: SW2.1, SW8.1, SW14.1, U3.12
COL2: SW3.1, SW9.1, SW15.1, SW19.S2, U3.11
COL3: SW4.1, SW10.1, SW16.1, SW20.1, U3.15
COL4: SW5.1, SW11.1, SW17.1, SW21.1, U3.16
COL5: SW6.1, SW12.1, SW18.1, SW22.S2, U3.17
COL_R0: SW28.1, SW34.1, SW40.1, U8.20
COL_R1: SW27.1, SW33.1, SW39.1, U8.19
COL_R2: SW26.1, SW32.1, SW38.1, SW44.S1, U8.18
COL_R3: SW25.1, SW31.1, SW37.1, SW43.1, U8.17
COL_R4: SW24.1, SW30.1, SW36.1, SW42.1, U8.16
COL_R5: SW23.1, SW29.1, SW35.1, SW41.S1, U8.15
ENABLE: Q2.1, R2.2, U3.28
ENABLE_R: Q4.1, R17.2, U8.13
ENC_A: SW19.A, SW22.A, U3.35
ENC_B: SW19.B, SW22.B, U3.36
ENC_RA: SW41.B, SW44.B, U8.8
ENC_RB: SW41.A, SW44.A, U8.7
EXT_R_VCC: D36.1, D37.1, D38.1, D39.1, D40.1, D41.1, J8.6, Q4.3
EXT_VCC: D12.1, D13.1, D14.1, D15.1, D16.1, D17.1, J3.6, Q2.3
GND: C1.2, C2.2, C3.2, C4.2, D12.3, D13.3, D14.3, D15.3, D16.3, D17.3, J1.2, J2.1, J3.1, J4.A1, J4.A12, J4.B1, J4.B12, J4.S1, J5.1, R2.1, R4.2, R5.1, R7.2, R8.2, R9.1, R10.1, R11.2, R12.2, SW19.C, SW22.C, SW51.2, U1.2, U2.1, U2.3, U3.1, U3.25, U3.37, U4.2
GND1: C5.2, C6.2, C7.2, C8.2, D36.3, D37.3, D38.3, D39.3, D40.3, D41.3, J6.2, J7.1, J8.1, J9.1, J10.A1, J10.A12, J10.B1, J10.B12, J10.S1, R14.1, R15.2, R17.1, R18.2, R19.2, R20.2, R22.2, R23.1, R24.1, SW41.C, SW44.C, SW53.2, U5.1, U5.3, U6.2, U7.2, U8.1, U8.25, U8.37
GPIO_A: J3.3, U3.26
GPIO_B: J3.2, U3.27
GPIO_C: J3.4, U3.20
GPIO_D: J3.5, U3.19
GPIO_RA: J8.3, U8.10
GPIO_RB: J8.2, U8.9
GPIO_RC: J8.4, U8.11
GPIO_RD: J8.5, U8.12
LED1: D26.2, U3.8
LED2: D27.2, U3.10
LED3: D28.2, U3.9
LED_DATA: D12.4, U3.18
LED_R1: D42.2, U8.36
LED_R2: D43.2, U8.35
LED_R3: D44.2, U8.34
LED_RDATA: D36.4, U8.26
unnamed: C3.1, D23.1, Q1.2, R1.1, U1.1
unnamed: C7.1, D24.1, Q3.2, R16.1, U6.1
unnamed: D1.1, SW3.2
unnamed: D1.2, SW2.2
unnamed: D2.1, SW7.2
unnamed: D2.2, SW18.2
unnamed: D3.1, SW19.S1
unnamed: D3.2, SW20.2
unnamed: D4.1, SW4.2
unnamed: D4.2, SW1.2
unnamed: D5.1, SW8.2
unnamed: D5.2, SW17.2
unnamed: D6.1, SW13.2
unnamed: D6.2, SW21.2
unnamed: D7.1, SW5.2
unnamed: D7.2, SW12.2
unnamed: D8.1, SW9.2
unnamed: D8.2, SW16.2
unnamed: D9.1, SW14.2
unnamed: D9.2, SW22.S1
unnamed: D10.1, SW6.2
unnamed: D10.2, SW11.2
unnamed: D11.1, SW10.2
unnamed: D11.2, SW15.2
unnamed: D12.2, D13.4
unnamed: D13.2, D14.4
unnamed: D14.2, D17.4
unnamed: D15.4, D16.2
unnamed: D16.4, D17.2
unnamed: D18.1, R13.1
unnamed: D19.1, SW41.S2
unnamed: D19.2, SW39.2
unnamed: D20.1, SW42.2
unnamed: D20.2, SW40.2
unnamed: D21.1, SW30.2
unnamed: D21.2, SW23.2
unnamed: D22.1, SW29.2
unnamed: D22.2, SW24.2
unnamed: D25.1, R3.1
unnamed: D26.1, R8.1
unnamed: D27.1, R11.1
unnamed: D28.1, R12.1
unnamed: D29.1, SW28.2
unnamed: D29.2, SW25.2
unnamed: D30.1, SW37.2
unnamed: D30.2, SW32.2
unnamed: D31.1, SW38.2
unnamed: D31.2, SW31.2
unnamed: D32.1, SW36.2
unnamed: D32.2, SW33.2
unnamed: D33.1, SW43.2
unnamed: D33.2, SW44.S2
unnamed: D34.1, SW35.2
unnamed: D34.2, SW34.2
unnamed: D35.1, SW27.2
unnamed: D35.2, SW26.2
unnamed: D36.2, D37.4
unnamed: D37.2, D38.4
unnamed: D38.2, D41.4
unnamed: D39.4, D40.2
unnamed: D40.4, D41.2
unnamed: D42.1, R18.1
unnamed: D43.1, R19.1
unnamed: D44.1, R20.1
unnamed: J2.2, U3.31
unnamed: J2.3, U3.32
unnamed: J4.A5, R10.2
unnamed: J4.B5, R9.2
unnamed: J9.2, U8.31
unnamed: J9.3, U8.32
unnamed: J10.A5, R23.2
unnamed: J10.B5, R24.2
unnamed: Q1.3, SW50.1
unnamed: Q3.3, SW52.1
unnamed: R1.2, U1.3
unnamed: R3.2, U2.7
unnamed: R5.2, U2.2
unnamed: R6.2, R7.1, U3.6
unnamed: R13.2, U5.7
unnamed: R14.2, U5.2
unnamed: R16.2, U6.3
unnamed: R21.2, R22.1, U8.6
unnamed: SW51.1, U3.21
unnamed: SW53.1, U8.21
ROW0: D1.3, D4.3, D7.3, U3.29
ROW1: D2.3, D5.3, D8.3, U3.30
ROW2: D3.3, D6.3, D9.3, U3.33
ROW3: D10.3, D11.3, U3.34
ROW_R0: D22.3, D29.3, D35.3, U8.5
ROW_R1: D30.3, D32.3, D34.3, U8.4
ROW_R2: D19.3, D20.3, D33.3, U8.3
ROW_R3: D21.3, D31.3, U8.2
USB-D+: J4.A6, J4.B6, U3.24, U4.3
USB-D-: J4.A7, J4.B7, U3.23, U4.6
USB_RD+: J10.A6, J10.B6, U7.4, U8.24
USB_RD-: J10.A7, J10.B7, U7.1, U8.23
VBAT: C2.1, J1.1, J5.2, R6.1, SW50.2, U2.5
VBAT_R: C6.1, J6.1, J7.2, R21.1, SW52.2, U5.5
VBUS: F1.2, J4.A4, J4.A9, J4.B4, J4.B9
VBUS_R: F2.2, J10.A4, J10.A9, J10.B4, J10.B9

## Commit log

2021-09-09 Tornblue rev0
    [outline.dxf, tornblue.dxf, tornblue.kicad_pcb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]
2021-09-28 Add 3d printed case files
    [Base.3mf, Plate.stl, Wall.3mf]
2021-09-29 Add 6 column wedge case
    [5_Base.3mf, 5_Plate.stl, 5_Wall.3mf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]
2021-09-29 Use m3 mounting holes
    [tornblue.kicad_pcb]
2021-09-29 Smooth board outline
    [tornblue.kicad_pcb]
2021-09-29 Change to lower profile reset switch
    [tornblue.kicad_pcb]
2021-09-30 Removed support for Kailh MX sockets
    It is not possible to include options for Kailh MX sockets, underglow
    LEDS and Panasonic EVQWGD001 encoder on the same PCB.
    [tornblue.kicad_pcb, tornblue.sch]
2021-09-30 Move holyiot module up 1.5mm
    [tornblue.kicad_pcb, tornblue.sch]
2021-10-10 Rearrange BAV70 grid
    [tornblue.kicad_pcb, tornblue.sch]
2021-10-10 Move BAV70 grid up 0.5mm
    [tornblue.kicad_pcb, tornblue.sch]
2021-10-10 Fix EVQWGD001 footprint
    [tornblue.kicad_pcb]
2021-10-10 Move underglow leds up 1mm
    [tornblue.kicad_pcb]
2021-10-10 Add battery pins + silk screen fixes
    [tornblue.kicad_pcb, tornblue.sch]
2021-10-10 Add power switch
    [tornblue.kicad_pcb, tornblue.sch]
2021-10-10 Silk screen fixes
    [tornblue.kicad_pcb]
2021-10-16 Add right edgecuts
    [tornblue.kicad_pcb]
2021-10-16 Add right schematic
    [tornblue.kicad_pcb, tornblue_right.sch]
2021-10-16 Placed components on the right side
    [tornblue.kicad_pcb, tornblue_right.sch]
2021-10-16 Add zones
    [tornblue.kicad_pcb]
2021-10-16 Fix encoder rotation
    [tornblue_right.sch]
2021-10-18 Routing key matrix
    [tornblue.kicad_pcb, tornblue_right.sch]
2021-11-21 Finish layout, via placement and silk screen
    [tornblue.kicad_pcb, tornblue.sch, tornblue_right.sch]
2021-11-21 Fix kibot config
    Command:
    ~/.local/bin/kicad-exports -d docs -b tornblue.kicad_pcb -e tornblue.sch -c kibot.yaml
    [tornblue_right.sch]
2021-11-21 Add elecrow files
    [tornblue.sch, tornblue_right.sch]
2021-11-27 Update to kicad 6
    [tornblue.kicad_sch, tornblue.sch, tornblue_right.kicad_sch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]
2021-11-28 Curved traces
2021-11-28 Update reset button
    [tornblue.kicad_sch, tornblue_right.kicad_sch]
2021-12-01 Fix 3d models without changing footrprint pads
    [tornblue.kicad_sch, tornblue_right.kicad_sch]
2021-12-01 Add powered by zmk silk
    [tornblue.kicad_sch, tornblue_right.kicad_sch]
2022-01-01 Update kibot for KiCad 6 and start elcrow bom
    Slightly hacky but running on osx:
    DYLD_FALLBACK_LIBRARY_PATH=/Applications/KiCad/KiCad.app/Contents/Frameworks:/usr/local/opt/python\@3.8/Frameworks/Python.framework/ PYTHONPATH=/Applications/KiCad/KiCad.app/Contents/Frameworks/Pytho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
    [tornblue.kicad_sch, tornblue_right.kicad_sch]
2022-01-04 Elecrow BOM
    [tornblue.kicad_sch, tornblue_right.kicad_sch]
2022-01-04 Fix gerbers for jlcpcb
    Need to remove the hatched ground fill to prevent the jlcpcb
    processing from timing out
2022-01-05 Add holes to the ground plane
2022-01-09 Download datasheets with kibot
    [tornblue.kicad_sch, tornblue_right.kicad_sch]
2022-01-09 r1 PCBA files for jlcpcb and elecrow
    [tornblue-bom.csv, tornblue.xlsx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]
2022-01-09 Move pcb files
    [tornblue-bom.csv, tornblue.kicad_sch, tornblue.xlsx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]
2022-01-09 Add fusion 360 model
    [tornblue r1.f3d]
2022-04-02 Updated fusion360 design file
    [tornblue r1.f3d]
2022-04-02 Updated files for 3d printed case
    [5_Base.3mf, 5_Edge.3mf, 5_Plate.3mf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]
2022-04-02 Remove old dxf files
    [outline.dxf, tornblue.dxf]
2022-04-23 Add interlocking joint
    [5_Base.3mf, 5_Edge.3mf]
2022-05-01 Fix case links
2022-07-04 Add stacked acrylic plate case
    [TornBlue Stacked Acrylic Plate Case.f3d]
2022-08-13 Fix stacked-acrylic images
    [StackedAcrylicCase.f3d]
2022-08-13 Add mini wedge case
    [5_Mini_Wedge.3mf]
2023-02-09 Remove hatched ground fill
    This causes jlcpcb site to timeout processing the gerbers, and you
    can't really see the hatched effect on the finished keyboard anyway.
2023-02-09 Add kibot as github workflow
    [tornblue-bom.csv, tornblue.xlsx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]
2023-02-25 Add 6 column 3d printed cases
    [5_Base.3mf, 5_Edge.3mf, 5_Mini_Wedge.3mf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]

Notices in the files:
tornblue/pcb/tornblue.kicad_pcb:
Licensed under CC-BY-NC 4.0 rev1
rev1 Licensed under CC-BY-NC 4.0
